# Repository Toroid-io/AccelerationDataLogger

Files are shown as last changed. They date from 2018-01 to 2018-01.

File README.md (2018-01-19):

# AccelerationDataLogger

**AccelerationDataLogger** provides a hardware-software bundle to
measure and log accelerations. Originally developed to measure
oscillations in engineering models, it may be used in the following
applications, among others:

 - Structural dynamics
 - Sports science
 - Simple vibration analysis
 - Fall detection
 - Wearables development
 - As an accelerometer playground

The board is capable of measuring **two accelerations simultaneously**
with a maximum sampling frequency of 800Hz, during 11 seconds. Longer
measurements are possible reducing the sampling rate, or using only one
accelerometer.

It currently uses jellybean parts as accelerometers. The board currently
supports the following breakout boards:
 - MPU6050 (GY-521 breakout)
 - ADXL345 (GY-291 and Sparkfun breakouts)

## Quick user manual
- Power the board using batteries or the USB cable.
- Fix the board into the structure or person.
- Calibrate the board by pressing the *Calibrate button*.
- Acquire the acceleration by pressing the *Acquire button*.
- Connect the board to your computer to download the data.

## The Hardware
You may find the KiCad schematic and board in the `Board` directory.

### Overview

The board does all the acquisition and storing procedure autonomously.
Hence, it may be battery powered during acquisition, and then connected
to a computer to download the data. In the current state, the board
requires at least 6.8V to work autonomously (this tension may be
provided by two LiPo cells or a 9V battery).

It has three pushable buttons, in order to reset the system, calibrate
the device and acquire data. A pushable switch enables or disables the
battery for autonomous mode.

The board may be connected to a computer using a USB micro-B cable.

That's all you need to know about the hardware!

### Memory

The board has 1MBit of RAM, where all the data is stored. Given that a
16-bit accelerometer provides 6 bytes of data for each measurement (plus
1 byte for the accelerometer ID), the board is capable of saving 18724
measurements.

That equals:
 - 11.7 seconds using two accelerometers at 800Hz
 - 23.4 seconds using one accelerometer at 800Hz
 - 6.24 minutes with one accelerometer at 50Hz
 - ...

## The Firmware

ChibiOS RTOS is used for the firmware. Tasks are used to separate the
acquisition of each sensor, write the RAM, and send measurements when
requested. Give a look into the `Firmware` folder.

## The acquisition software

A simple interface has been written in Qt C++, in order to download and
preview the data. The interface looks like this:

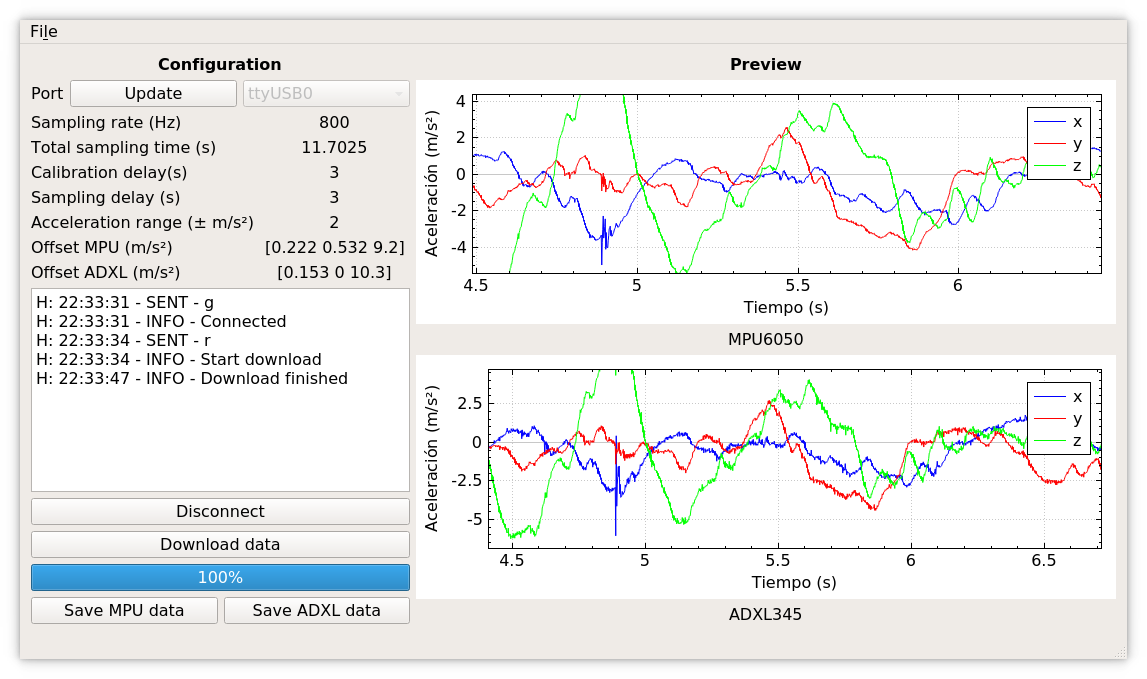
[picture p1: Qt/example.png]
Software screenshot


Currently, the interface only allows to connect and download the data
from the board. Future versions will allow the modification of some
parameters, such as the sampling frequency.

## I want one!

### Build One

Bare PCB

You can build your own AccelerationDataLogger. Mounting the PCB requires
average soldering skills (0603 footprints and LQFP packages), but it is
the cheap way to go.

You can get the PCB from [OSH
Park](https://oshpark.com/shared_projects/0VAEaJ3K), or generate your
own Gerbers from the PCB. The BOM is in the `Board` directory.

### Get one built

We can send you a populated PCB. Just contact us at `admin [at]
toroid.io` for a quote.

## Development

### Contribute

Do you want to add or request a new feature? Did you find a bug in the
code? Create an issue or a pull request! All contributions are welcome.

### Future features

A non-exhaustive list of future features:
 - Add support to more accelerometers
 - Use a coin cell to power the system autonomously
 - Reduce the size of the board
 - Implement other MEMS features (DMP, fall detection)

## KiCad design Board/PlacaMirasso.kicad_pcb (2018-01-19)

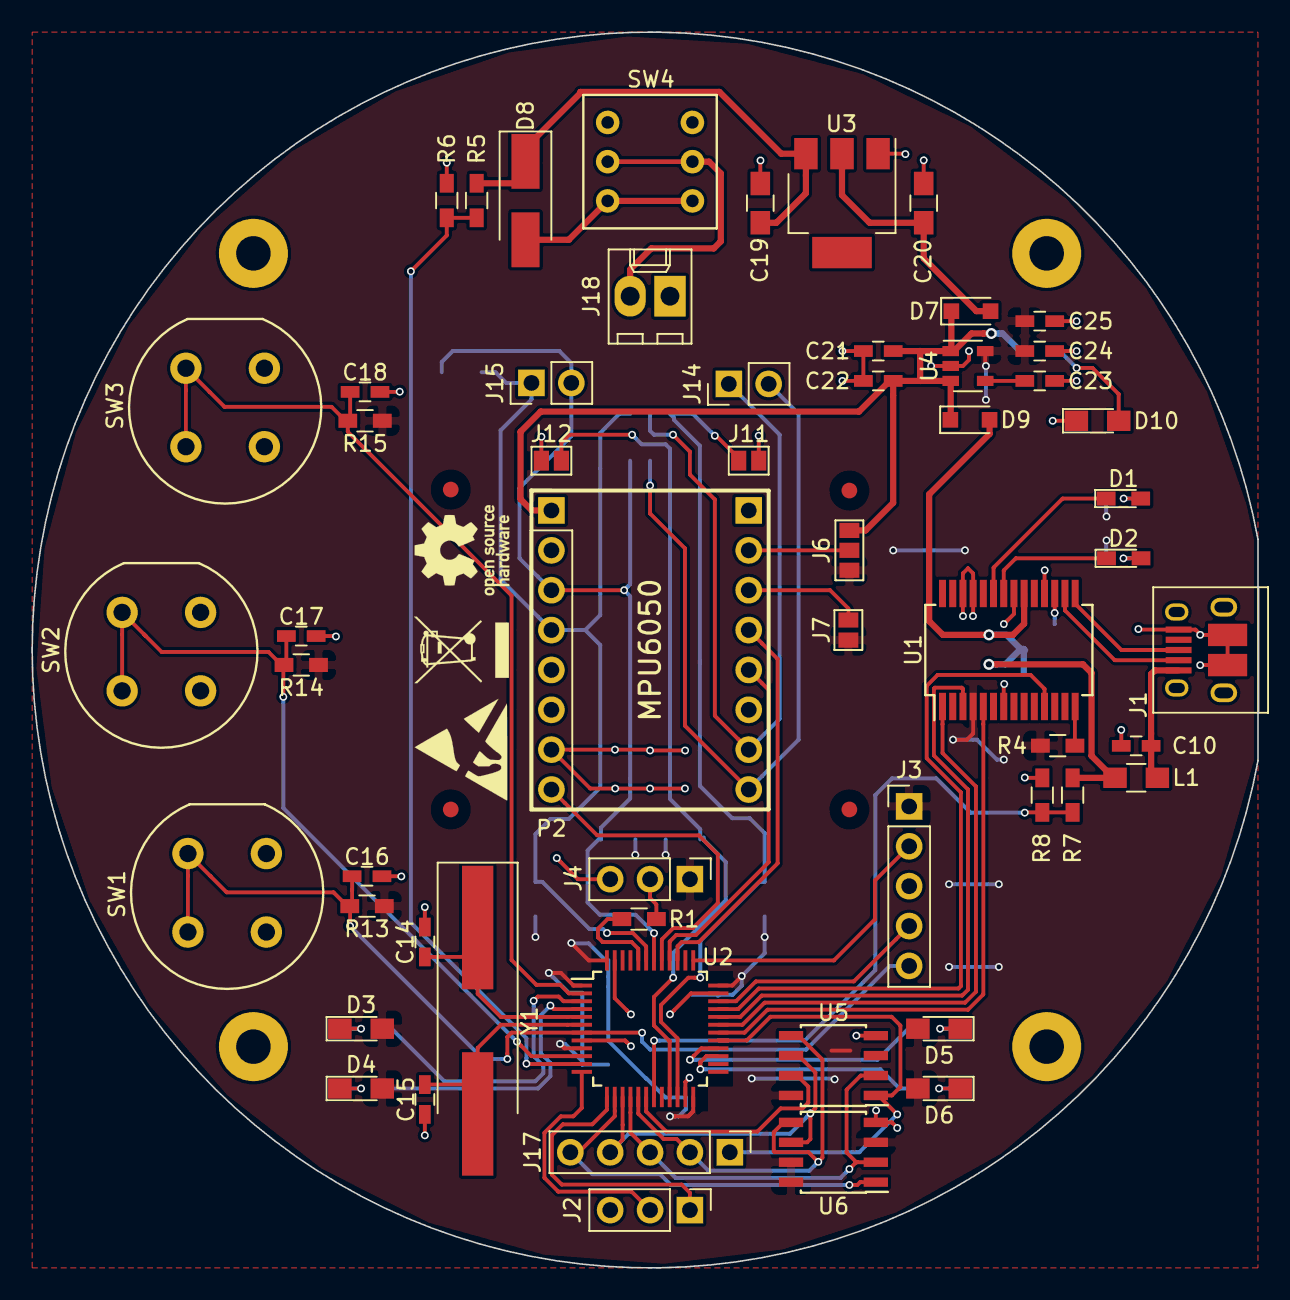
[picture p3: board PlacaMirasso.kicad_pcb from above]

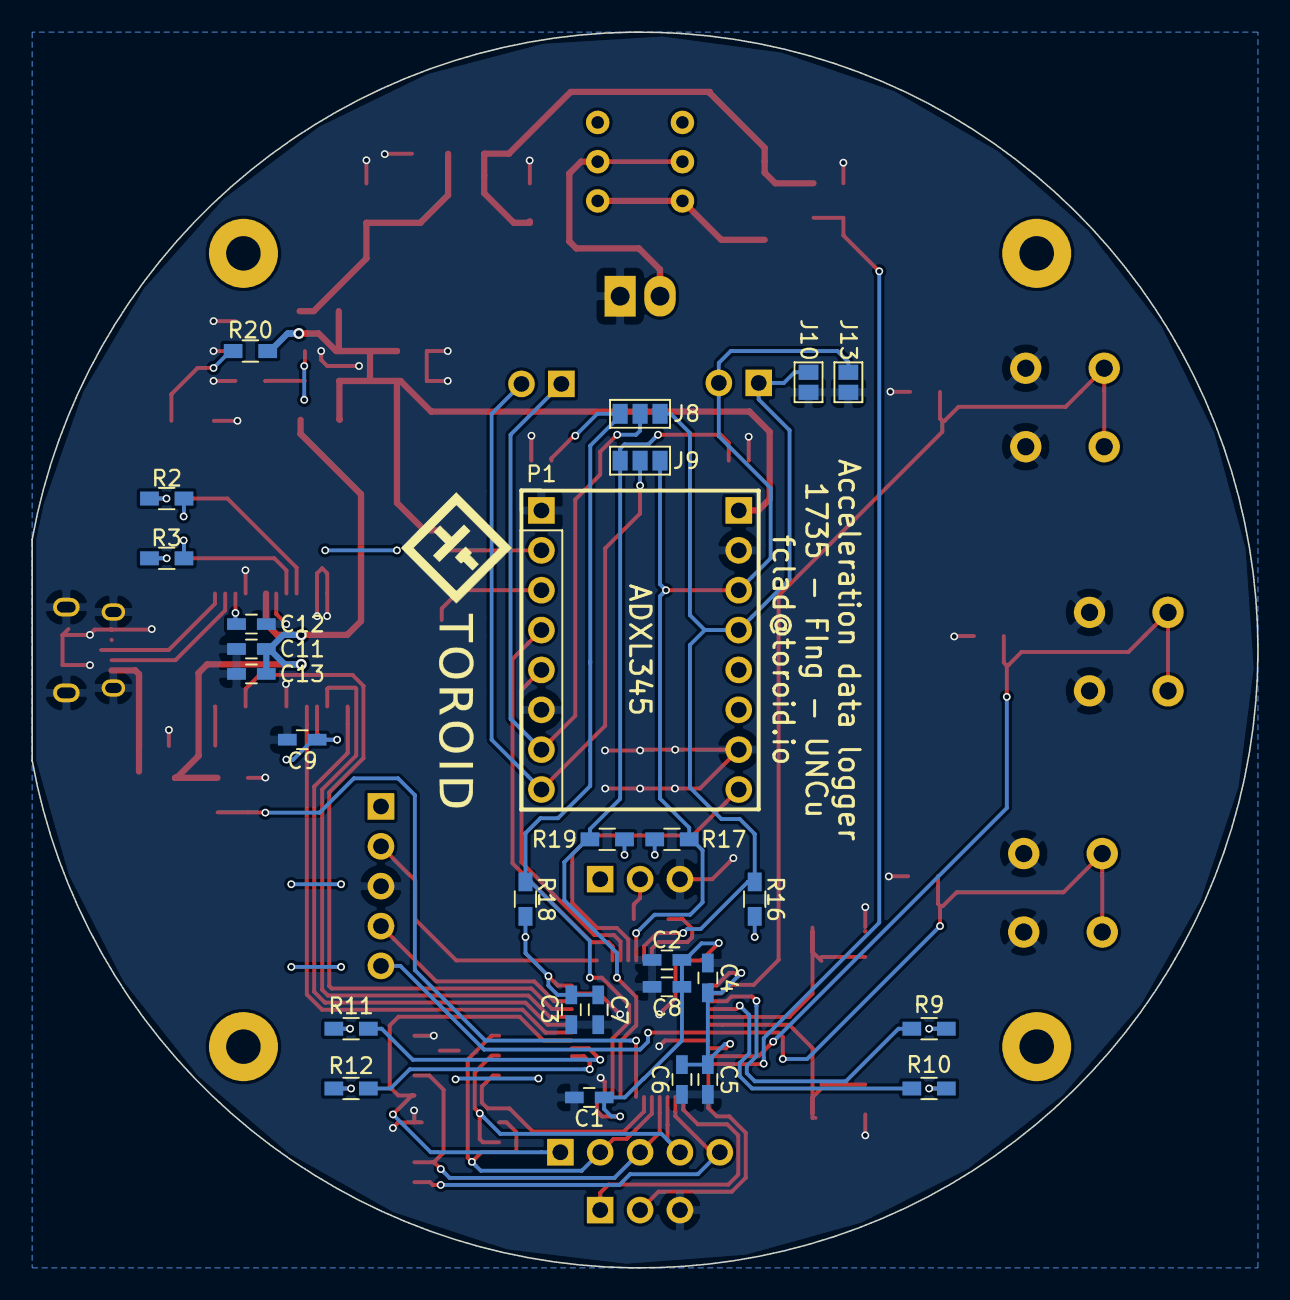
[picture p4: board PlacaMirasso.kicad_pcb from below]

Board: 2 copper layers, 78.1 x 78.7 mm, 93 parts (28 on the bottom side), 61 nets.

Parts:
C1, C2, C3, C4, C9, C11, C12, C16, C17, C18, C22, C25: 100nF; C_0603_HandSoldering
C5, C10, C23: 10nF_X7R; C_0603_HandSoldering
C6, C21, C24: 1uF_X5R; C_0603_HandSoldering
C7, C8, C13: 4.7uF; C_0603_HandSoldering
C14, C15: 10pF; C_0603_HandSoldering
C19, C20: 10uF; C_0805_HandSoldering
D1, D2: LED; LED_0603_HandSoldering
D3, D4, D5, D6, D10: LED; LED_0805_HandSoldering
D7, D9: BAT60JFILM; D_SOD-323_HandSoldering
D8: STPS2L30A; D_SMA_Handsoldering
J1: USB_OTG; USB_Micro-B_10103594-0001LF
J2: DEBUG; Pin_Header_Straight_1x03_Pitch2.54mm
J3: SWD; Pin_Header_Straight_1x05_Pitch2.54mm
J4: BOOT_JMP; Pin_Header_Straight_1x03_Pitch2.54mm
J6, J8, J9: GS3
J7, J10, J11, J12, J13: GS2
J14: ANALIZER_ADXL; Pin_Header_Straight_1x02_Pitch2.54mm
J15: ANALIZER_MPU; Pin_Header_Straight_1x02_Pitch2.54mm
J17: SPI_ANALYZER; Pin_Header_Straight_1x05_Pitch2.54mm
J18: BAT; Molex_KK-6410-02_02x2.54mm_Straight
L1: MI0805K400R-10; L_0805_HandSoldering
MNT1, MNT2, MNT3, MNT4: MountHole; MountingHole_2.2mm_M2_Pad
P1: ADXL345; Socket_Strip_Straight_1x08_Pitch2.54mm
P2: MPU_6050; Socket_Strip_Straight_1x08_Pitch2.54mm
R1, R4, R6: 10k; R_0603_HandSoldering
R2, R3, R9, R10, R11, R12, R20: 1k1; R_0603_HandSoldering
R5, R8: 47k; R_0603_HandSoldering
R7: 39k; R_0603_HandSoldering
R13, R14, R15: 100k; R_0603_HandSoldering
R16, R17, R18, R19: 2k2; R_0603_HandSoldering
SW1, SW2, SW3: SW_Push_Dual; Push_E-Switch_KS01Q01
SW4: SW_DPDT_x2; Pushbutton-MHPS2283-DPDT
U1: FT232RL; SSOP-28_5.3x10.2mm_Pitch0.65mm
U2: STM32F072CBTx; LQFP-48_7x7mm_Pitch0.5mm
U3: LD1117S50TR; SOT-223
U4: LD3985M33R_SOT23; SOT-23-5
U5: 23LCRAM; SOIC-8_3.9x4.9mm_Pitch1.27mm
U6: 25LC_EEPROM; SOIC-8_3.9x4.9mm_Pitch1.27mm
Y1: 9C-8.000MBBK-T; Crystal_SMD_HC49-SD_HandSoldering
fid1, fid2, fid3, fid4: fiducial; Fiducial_1mm_Dia_2.54mm_Outer_CopperTop

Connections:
+3V3: C1.1, C2.1, C3.1, C4.1, C5.1, C6.1, C7.1, C8.1, C9.1, C24.1, C25.1, D3.2, D4.2, D5.2, D6.2, J3.1, J4.1, J6.1, J7.1, R2.1, R3.1, R4.1, R13.1, R14.1, R15.1, R16.2, R17.2, R18.2, R19.2, U1.4, U2.1, U2.9, U2.24, U2.36, U2.48, U4.5, U5.8, U6.3, U6.7, U6.8
+5V: C21.1, C22.1, D7.1, D9.1, J6.3, P2.1, R20.1, U4.1, U4.3
/BOOT_0: J4.2, R1.2
/CS_ADXL: J7.2, P1.3
/CTS_uC: U1.3, U2.32
/DEBUG_RX_uC: J2.1, U2.13
/DEBUG_TX_uC: J2.2, U2.12
/E5V: C20.1, D7.2, U3.2
/I2C1_SCL: J9.1, J13.1, J15.2, P2.3, R17.1, U2.42
/I2C1_SDA: J8.1, J10.1, J15.1, P2.4, R16.1, U2.43
/I2C2_SCL: J9.3, J12.1, R19.1, U2.21
/I2C2_SDA: J8.3, J11.1, R18.1, U2.22
/INT1_ADXL: P1.4, U2.39
/INT2_ADXL: P1.5, U2.40
/INT_MPU: P2.8, U2.41
/LED_1: R9.2, U2.3
/LED_2: R10.2, U2.4
/LED_3: R11.2, U2.28
/LED_4: R12.2, U2.27
/RESET: C16.1, J3.5, R13.2, SW1.2, SW1.4, U2.7
/RTS_uC: U1.11, U2.33
/Rx_uC: U1.1, U2.31
/SCL_ADXL: J9.2, J14.2, P1.8
/SDA_ADXL: J8.2, J14.1, P1.7
/SPI1_CS_1: J17.5, U2.14, U6.1
/SPI1_CS_2: J17.1, U2.29, U5.1
/SPI1_HOLD: U2.18, U5.7
/SPI1_MISO: J17.3, U2.16, U5.2, U6.2
/SPI1_MOSI: J17.2, U2.17, U5.5, U6.5
/SPI1_SCK: J17.4, U2.15, U5.6, U6.6
/SWCLK: J3.2, U2.37
/SWDIO: J3.4, U2.34
/Tx_uC: U1.5, U2.30
/U5V: C11.1, C13.1, D9.2, L1.1, R7.1, U1.20
/USR_BTN_1: C17.1, R14.2, SW2.2, SW2.4, U2.10
/USR_BTN_2: C18.1, R15.2, SW3.2, SW3.4, U2.2
/VBAT_ADC: R5.2, R6.1, U2.11
/VCC_ADXL: J6.2, P1.2
/VIN: C19.1, D8.1, R5.1, U3.3
/VUSB_ADC: R7.2, R8.1, U2.19
GND: C1.2, C2.2, C3.2, C4.2, C5.2, C6.2, C7.2, C8.2, C9.2, C10.2, C11.2, C12.2, C13.2, C14.2, C15.2, C16.2, C17.2, C18.2, C19.2, C20.2, C21.2, C22.2, C23.2, C24.2, C25.2, D10.1, J1.5, J1.6, J2.3, J3.3, J4.3, J10.2, J11.2, J12.2, J13.2, J18.1, P1.1, P1.6, P2.2, P2.7, R6.2, R8.2, SW1.1, SW1.3, SW2.1, SW2.3, SW3.1, SW3.3, U1.7, U1.18, U1.21, U1.25, U1.26, U2.8, U2.23, U2.35, U2.47, U3.1, U4.2, U5.4, U6.4
unnamed: C10.1, J1.1, L1.2
unnamed: C12.1, U1.17
unnamed: C14.1, U2.5, Y1.1
unnamed: C15.1, U2.6, Y1.2
unnamed: C23.1, U4.4
unnamed: D1.1, U1.23
unnamed: D1.2, R2.2
unnamed: D2.1, U1.22
unnamed: D2.2, R3.2
unnamed: D3.1, R9.1
unnamed: D4.1, R10.1
unnamed: D5.1, R11.1
unnamed: D6.1, R12.1
unnamed: D8.2, SW4.3, SW4.6
unnamed: D10.2, R20.2
unnamed: J1.2, U1.16
unnamed: J1.3, U1.15
unnamed: J18.2, SW4.2, SW4.5
unnamed: R1.1, U2.44
unnamed: R4.2, U1.14

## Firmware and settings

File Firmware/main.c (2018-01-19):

/* TODO
 * - Config variable sensors range (EEPROM config)
 * - Fix UART unhandled exception when system is not compiled with debug options
 */
#include "ch.h"
#include "hal.h"
#include "ChibiOS/os/hal/lib/streams/chprintf.h"
#include <string.h>
#include "MEMS/MPU6050.h"
#include "MEMS/ADXL345.h"
#include "EEPROM/StaticSystemConfig.h"


/*===========================================================================*/
/* Global variables - RTOS stuff                                             */
/*===========================================================================*/

volatile enum state {IDLE,
	CALIBRATION,
	START_ACQUISITION,
	ACQUISITION,
	DOWNLOAD_CONFIG,
	SAVE_CONFIG,
	PRINT_DATA,
	PRINT_CONFIG} systemState;
static MUTEX_DECL(systemState_mutex);

struct configStructure sysConf;

/* the mailboxes are used to send information into the spi thread */
#define NUM_BUFFERS 4
#define BUFFERS_SIZE 8
static char buffers[NUM_BUFFERS][BUFFERS_SIZE];
static msg_t free_buffers_queue[NUM_BUFFERS];
static mailbox_t free_buffers;
static msg_t filled_buffers_queue[NUM_BUFFERS];
static mailbox_t filled_buffers;

/* recvBuffer is used to store data coming from the UART (configs) */
uint8_t recvBuffer[32];

#define SPI_RAM_SIZE 128*1024
/* Amount of memory used in the SPI RAM */
/* This variable does not need a mutex by design. Mutual exclusion is handled by
 * systemState
 */
volatile int32_t memoryCounter;

/* Various semaphores to synchronize stuff */
static BSEMAPHORE_DECL(printMutex, 1);
static threads_queue_t threadQueue;

/* ADC variables used to test USB, Battery voltage, VRefInt, Temp */
#define ADC_GRP_NUM_CHANNELS   2
#define ADC_GRP_BUF_DEPTH      128
static adcsample_t samples[ADC_GRP_NUM_CHANNELS * ADC_GRP_BUF_DEPTH];

/*===========================================================================*/
/* Callbacks                                                                 */
/*===========================================================================*/

/* Triggered when the calibration button is released.*/
static void extcb1(EXTDriver *extp, expchannel_t channel) {
  (void)extp;
  (void)channel;
  chSysLockFromISR();
  if (systemState == IDLE)
	  systemState = CALIBRATION;
  chSysUnlockFromISR();
}

/* Triggered when the acquisition button is released.*/
static void extcb2(EXTDriver *extp, expchannel_t channel) {
  (void)extp;
  (void)channel;
  chSysLockFromISR();
  if (systemState == IDLE)
	  systemState = START_ACQUISITION;
  chSysUnlockFromISR();
}

static void led2off(void *arg);
static void gpt3cb(GPTDriver *gptp) {
	(void)gptp;
	static virtual_timer_t vt;
	palClearPad(GPIOC, GPIOC_LED_2);
	chSysLockFromISR();
	chThdDequeueAllI(&threadQueue, 0);
	/* LED2 set to OFF after 800uS.*/
	chVTResetI(&vt);
	chVTSetI(&vt, US2ST(800), led2off, NULL);
	chSysUnlockFromISR();
}

/*
 * This callback is invoked when a transmission buffer has been completely
 * read by the driver.
 */
static void txend1(UARTDriver *uartp) {
  (void)uartp;
  //palSetPad(GPIOC, GPIOC_LED4);
}

/*
 * This callback is invoked when a transmission has physically completed.
 */
static void led3off(void *arg);
static void txend2(UARTDriver *uartp) {
  (void)uartp;
  static virtual_timer_t vt3;
  palClearPad(GPIOB, GPIOB_LED_3);
  chSysLockFromISR();
  chVTResetI(&vt3);
  chVTSetI(&vt3, US2ST(200), led3off, NULL);
  chSysUnlockFromISR();
}

/*
 * This callback is invoked on a receive error, the errors mask is passed
 * as parameter.
 */
static void rxerr(UARTDriver *uartp, uartflags_t e) {
  (void)uartp;
  (void)e;
}

/*
 * This callback is invoked when a character is received but the application
 * was not ready to receive it, the character is passed as parameter.
 */
static void rxchar(UARTDriver *uartp, uint16_t c) {
  (void)uartp;
  (void)c;
  chSysLockFromISR();
  if (systemState != IDLE) {
	  chSysUnlockFromISR();
	  return;
  }
  switch (c) {
  case 'r':
  case 'R':
	  systemState = PRINT_DATA;
	  chBSemSignalI(&printMutex);
	  break;
  case 'g':
  case 'G':
	  systemState = PRINT_CONFIG;
	  chBSemSignalI(&printMutex);
	  break;
  case 'c':
  case 'C':
	  systemState = DOWNLOAD_CONFIG;
	  uartStartSendI(&UARTD1, 15, "--Send Config--");
	  uartStartReceiveI(&UARTD1,
			    sizeof(struct configStructure),
			    (void *)recvBuffer);
	  break;
  default:
	  break;
  }
  chSysUnlockFromISR();
}

/*
 * This callback is invoked when a receive buffer has been completely written.
 */
static void rxend(UARTDriver *uartp) {
  (void)uartp;
  chSysLockFromISR();
  if (systemState != DOWNLOAD_CONFIG)
	  osalSysHalt("UART rx was not expected");
  if(checkSystemConfig((struct configStructure *)recvBuffer)) {
	  uartStartSendI(&UARTD1, 16, "--Config ERROR--");
	  systemState = IDLE;
  } else {
	  uartStartSendI(&UARTD1, 13, "--Config OK--");
	  systemState = SAVE_CONFIG;
	  memcpy(&sysConf, recvBuffer, sizeof(struct configStructure));
  }
  chSysUnlockFromISR();
}

/*
 * This callback is invoked when configured timeout reached.
 */
static void rxtimeout(UARTDriver *uartp) {
  (void)uartp;
  chSysLockFromISR();
  /* We can get here because commands triggered this interrupt instead of data */
  if (systemState == DOWNLOAD_CONFIG) {
	  uartStopReceiveI(&UARTD1);
	  uartStartSendI(&UARTD1, 18, "--Config TIMEOUT--");
	  systemState = IDLE;
  }
  chSysUnlockFromISR();
}

/*===========================================================================*/
/* Peripherals config structures                                             */
/*===========================================================================*/

static const I2CConfig i2ccfg1 = {
	0x20803C54, // Normal mode, 100kHz
	0,
	0
};

static const I2CConfig i2ccfg2 = {
	0x80201619, // Normal mode, 100kHz
	0,
	0
};
static const SPIConfig eepromSPI = {
	NULL,
	GPIOA,
	GPIOA_SPI_CS_1,
	SPI_CR1_BR_2 | SPI_CR1_BR_1,
	SPI_CR2_DS_2 | SPI_CR2_DS_1 | SPI_CR2_DS_0
};

static const SPIConfig ramSPI = {
	NULL,
	GPIOA,
	GPIOA_SPI_CS_2,
	SPI_CR1_BR_2 | SPI_CR1_BR_1,
	SPI_CR2_DS_2 | SPI_CR2_DS_1 | SPI_CR2_DS_0
};

static const EXTConfig extcfg = {
  {
    {EXT_CH_MODE_RISING_EDGE | EXT_CH_MODE_AUTOSTART | EXT_MODE_GPIOA, extcb1},
    {EXT_CH_MODE_DISABLED, NULL},
    {EXT_CH_MODE_DISABLED, NULL},
    {EXT_CH_MODE_DISABLED, NULL},
    {EXT_CH_MODE_DISABLED, NULL},
    {EXT_CH_MODE_DISABLED, NULL},
    {EXT_CH_MODE_DISABLED, NULL},
    {EXT_CH_MODE_DISABLED, NULL},
    {EXT_CH_MODE_DISABLED, NULL},
    {EXT_CH_MODE_DISABLED, NULL},
    {EXT_CH_MODE_DISABLED, NULL},
    {EXT_CH_MODE_DISABLED, NULL},
    {EXT_CH_MODE_DISABLED, NULL},
    {EXT_CH_MODE_RISING_EDGE | EXT_CH_MODE_AUTOSTART | EXT_MODE_GPIOC, extcb2},
    {EXT_CH_MODE_DISABLED, NULL},
    {EXT_CH_MODE_DISABLED, NULL},
    {EXT_CH_MODE_DISABLED, NULL},
    {EXT_CH_MODE_DISABLED, NULL},
    {EXT_CH_MODE_DISABLED, NULL},
    {EXT_CH_MODE_DISABLED, NULL},
    {EXT_CH_MODE_DISABLED, NULL},
    {EXT_CH_MODE_DISABLED, NULL},
    {EXT_CH_MODE_DISABLED, NULL}
  }
};

static const GPTConfig gpt3cfg = {
  100000, // 100kHz timer clock.
  gpt3cb,
  0, 0
};

static const ADCConversionGroup adcgrpcfg = {
  TRUE,
  ADC_GRP_NUM_CHANNELS,
  NULL,
  NULL,
  ADC_CFGR1_CONT | ADC_CFGR1_RES_12BIT,             /* CFGR1 */
  ADC_TR(0, 0),                                     /* TR */
  ADC_SMPR_SMP_239P5,                               /* SMPR */
  ADC_CHSELR_CHSEL1 | ADC_CHSELR_CHSEL9
};

static UARTConfig uart_cfg_1 = {
  txend1,
  txend2,
  rxend,
  rxchar,
  rxerr,
  rxtimeout,
  115200*3,
  115200,
  USART_CR1_RTOIE,
  USART_CR2_LINEN | USART_CR2_RTOEN,
  0
};

/*===========================================================================*/
/* Functions                                                                 */
/*===========================================================================*/
void modifyAxis(int16_t *ax, int16_t *ay, int16_t *az)
{
	uint16_t tmp;
	*az= -*az;
	tmp = *ax;
	*ax = -*ay;
	*ay = -tmp;
}

void saturateInt16(int32_t *atmp, int16_t *acc)
{
	for (uint8_t i = 0; i < 3; ++i) {
		if (atmp[i] > INT16_MAX)
			acc[i] = INT16_MAX;
		else if (atmp[i] < INT16_MIN)
			acc[i] = INT16_MIN;
		else
			acc[i] = (int16_t)atmp[i];
	}
}

void exponentialFilter(int32_t *atmp, int32_t *g, int16_t *acc)
{
	/* Numerator and denominator values of the exponential filter */
	/* The calculation of the numerator gives a filter time-constant of 75 ms */
	int32_t num, den;
	den = 1000;
	num = (7500 * den) / (7500 + 100000 / sysConf.samplingSpeed);
	for (uint8_t i = 0; i < 3; ++i) {
	    g[i] = (g[i] * num + (den - num) * acc[i]) / den;
	    atmp[i] = acc[i] - g[i];
	}
	saturateInt16(atmp, acc);
}

static void led2off(void *arg) {
  (void)arg;
  palSetPad(GPIOC, GPIOC_LED_2);
}

static void led3off(void *arg) {
  (void)arg;
  palSetPad(GPIOB, GPIOB_LED_3);
}


static void blinkAllLeds(void){
  for (int i = 0; i < 2; ++i) {
    palClearPad(GPIOC, GPIOC_LED_1);
    palClearPad(GPIOC, GPIOC_LED_2);
    palClearPad(GPIOB, GPIOB_LED_3);
    palClearPad(GPIOB, GPIOB_LED_4);
    osalThreadSleepMilliseconds(100);
    palSetPad(GPIOC, GPIOC_LED_1);
    palSetPad(GPIOC, GPIOC_LED_2);
    palSetPad(GPIOB, GPIOB_LED_3);
    palSetPad(GPIOB, GPIOB_LED_4);
    osalThreadSleepMilliseconds(100);
  }
}

static void I2CInit(void)
{
	/*
	 * Check if the I2C is clogged and send some SCK pulses to release it
	 */

	if (!palReadPad(GPIOB, GPIOB_I2C1_SDA)) {
		for (int i  = 0; i < 16; ++i) {
			palClearPad(GPIOB, GPIOB_I2C1_SCL);
			osalThreadSleepMilliseconds(1);
			palSetPad(GPIOB, GPIOB_I2C1_SCL);
			osalThreadSleepMilliseconds(1);
		}
	}
	if (!palReadPad(GPIOB, GPIOB_I2C2_SDA)) {
		for (int i  = 0; i < 16; ++i) {
			palClearPad(GPIOB, GPIOB_I2C2_SCL);
			osalThreadSleepMilliseconds(1);
			palSetPad(GPIOB, GPIOB_I2C2_SCL);
			osalThreadSleepMilliseconds(1);
		}
	}

	/*
	 * Activates the I2C driver in hardware mode
	 */
	palSetPadMode(GPIOB, GPIOB_I2C1_SCL, PAL_MODE_ALTERNATE(1) |
		      PAL_STM32_OSPEED_HIGHEST | PAL_STM32_OTYPE_OPENDRAIN | PAL_STM32_PUPDR_PULLUP);
	palSetPadMode(GPIOB, GPIOB_I2C1_SDA, PAL_MODE_ALTERNATE(1) |
		      PAL_STM32_OSPEED_HIGHEST | PAL_STM32_OTYPE_OPENDRAIN | PAL_STM32_PUPDR_PULLUP);
	palSetPadMode(GPIOB, GPIOB_I2C2_SCL, PAL_MODE_ALTERNATE(1) |
		      PAL_STM32_OSPEED_HIGHEST | PAL_STM32_OTYPE_OPENDRAIN | PAL_STM32_PUPDR_PULLUP);
	palSetPadMode(GPIOB, GPIOB_I2C2_SDA, PAL_MODE_ALTERNATE(1) |
		      PAL_STM32_OSPEED_HIGHEST | PAL_STM32_OTYPE_OPENDRAIN | PAL_STM32_PUPDR_PULLUP);
	i2cStart(&I2CD1, &i2ccfg1);
	i2cStart(&I2CD2, &i2ccfg2);
}

static void calibrateSensors(void)
{
  uint16_t i;
  int16_t ax, ay, az;
  int32_t calibrationAccADXL[3] = {0, 0, 0};
  int32_t calibrationAccMPU[3] = {0, 0, 0};

  /* Calibration loop */
  for (i = 0; i < 128; ++i) {
    palClearPad(GPIOC, GPIOC_LED_2);
    chThdSleepMilliseconds(10);
    palSetPad(GPIOC, GPIOC_LED_2);
    MPU6050_getAcceleration(&ax, &ay, &az);
    calibrationAccMPU[0] += ax;
    calibrationAccMPU[1] += ay;
    calibrationAccMPU[2] += az;
    ADXL345_getAcceleration(&ax, &ay, &az);
    modifyAxis(&ax, &ay, &az);
    calibrationAccADXL[0] += ax;
    calibrationAccADXL[1] += ay;
    calibrationAccADXL[2] += az;
    chThdSleepMilliseconds(10);
  }

  sysConf.calibrationMPU[0] = calibrationAccMPU[0] / 128;
  sysConf.calibrationMPU[1] = calibrationAccMPU[1] / 128;
  sysConf.calibrationMPU[2] = calibrationAccMPU[2] / 128;

  sysConf.calibrationADXL[0] = calibrationAccADXL[0] / 128;
  sysConf.calibrationADXL[1] = calibrationAccADXL[1] / 128;
  sysConf.calibrationADXL[2] = calibrationAccADXL[2] / 128;

  saveSystemConfigEEPROM(&eepromSPI, &sysConf);

}

void createMailboxes(void)
{
	chMBObjectInit(&filled_buffers, filled_buffers_queue, NUM_BUFFERS);
	chMBObjectInit(&free_buffers, free_buffers_queue, NUM_BUFFERS);
	for (uint8_t i = 0; i < NUM_BUFFERS; i++)
		(void)chMBPost(&free_buffers, (msg_t)&buffers[i], TIME_INFINITE);
}

static void resetAllMailboxes(void)
{
	chMBReset(&free_buffers);
	chMBReset(&filled_buffers);
	createMailboxes();
}

static void sensorStartup(void)
{
	/* Initialize MPU */
	MPU6050_reset();
	chThdSleepMilliseconds(100);
	MPU6050_resetGyroscopePath();
	MPU6050_resetAccelerometerPath();
	MPU6050_resetTemperaturePath();
	chThdSleepMilliseconds(100);
	MPU6050_initialize();
	MPU6050_setStandbyXGyroEnabled(true);
	MPU6050_setStandbyYGyroEnabled(true);
	MPU6050_setStandbyZGyroEnabled(true);
	chThdSleepMilliseconds(100);
	// verify connection
	while (!MPU6050_testConnection()) {
		chprintf((BaseSequentialStream *)&SD2,"MPU FAIL\r\n");
		chThdSleepMilliseconds(1000);
	}
	chprintf((BaseSequentialStream *)&SD2,"MPU OK\r\n");

	/* Initialize ADXL345 */
	ADXL345_initialize();
	chThdSleepMilliseconds(100);
	// verify connection
	while (!ADXL345_testConnection()) {
		chprintf((BaseSequentialStream *)&SD2,"ADXL FAIL\r\n");
		chThdSleepMilliseconds(1000);
	}
	chprintf((BaseSequentialStream *)&SD2,"ADXL OK\r\n");
}

void getVoltages(uint16_t *vusb, uint16_t *vbat)
{
	uint32_t usbtmp = 0;
	uint32_t battmp = 0;
	/* Samples are alternating: vbat, vusb, vbat... */
	for(uint8_t i = 0; i < ADC_GRP_BUF_DEPTH; ++i) {
		battmp += samples[ADC_GRP_NUM_CHANNELS*i];
		usbtmp += samples[ADC_GRP_NUM_CHANNELS*i + 1];
	}
	battmp /= ADC_GRP_BUF_DEPTH;
	usbtmp /= ADC_GRP_BUF_DEPTH;

	/* Reference voltage is corrected to handle resistor offset
	 * (instead of 3300). Voltages are in mV.
	 */
	battmp = (battmp * 3394 * 57) / (4096 * 10);
	usbtmp = (usbtmp * 3327 * 86) / (4096 * 47);

	*vusb = (uint16_t)usbtmp;
	*vbat = (uint16_t)battmp;

	////chprintf((BaseSequentialStream *)&SD2,"USB: %u - BAT: %u\r\n",
	//	 *vusb, *vbat);
	return;
}

uint8_t checkVoltageLevel(void)
{
	uint16_t vusb, vbat;
	getVoltages(&vusb, &vbat);
	/* When running with USB voltage should not be a problem */
	if (vusb > 4000)
		return 0;
	  /* When running on batteries, 6.8V seems a logic voltage threshold */
	if (vbat < 6800) {
		return 1;
	}
	return 0;
}


/*===========================================================================*/
/* Threads                                                                   */
/*===========================================================================*/
/*
 * State machine thread
 */
static THD_WORKING_AREA(waThread0, 0x200);
static THD_FUNCTION(Thread0, arg) {
	(void)arg;
	uint32_t timerPeriod;
	while (true) {
		chMtxLock(&systemState_mutex);
		switch(systemState) {
		case IDLE:
		default:
			break;
		case CALIBRATION:
			chprintf((BaseSequentialStream *)&SD2,"Calibration...\r\n");
			for (uint8_t i = 0; i < 10*sysConf.calibrationDelay; i++) {
				palClearPad(GPIOC, GPIOC_LED_2);
				chThdSleepMilliseconds(50);
				palSetPad(GPIOC, GPIOC_LED_2);
				chThdSleepMilliseconds(50);

			}
			calibrateSensors();
			chprintf((BaseSequentialStream *)&SD2,"Calibration DONE\r\n");
			systemState = IDLE;
			break;
		case START_ACQUISITION:
			chprintf((BaseSequentialStream *)&SD2,"Acquisition...\r\n");
			for (uint8_t i = 0; i < 10*sysConf.acquisitionDelay; i++) {
				palClearPad(GPIOC, GPIOC_LED_2);
				chThdSleepMilliseconds(50);
				palSetPad(GPIOC, GPIOC_LED_2);
				chThdSleepMilliseconds(50);

			}
			memoryCounter = 0;
			systemState = ACQUISITION;
			/* Calculate the new timer period */
			timerPeriod = 100000/sysConf.samplingSpeed - 1;
			chprintf((BaseSequentialStream *)&SD2,"Timer period %u\r\n", (uint16_t)timerPeriod);
			/* Start the timer */
			gptStartContinuous(&GPTD3, (uint16_t) timerPeriod);
			break;
		case ACQUISITION:
			/* Nothing to do here
			 * State changement will be done in the RAM write task
			 */
			break;
		case DOWNLOAD_CONFIG:
			/* Nothing to do here
			 * State changement will be done in the UART callbacks
			 */
			break;
		case SAVE_CONFIG:
			/* We have a new config, save it in the EEPROM */
			saveSystemConfigEEPROM(&eepromSPI, &sysConf);
			/* Discard all measurements */
			memoryCounter = 0;
			systemState = IDLE;
			break;
		case PRINT_DATA:
			/* Nothing to do here
			 * Mutex will be released in ISR callback
			 * State will change in UART write task
			 */
			break;
		case PRINT_CONFIG:
			/* Nothing to do here
			 * Mutex will be released in ISR callback
			 * State will change in UART write task
			 */
			break;
		}
		chMtxUnlock(&systemState_mutex);
		chThdSleepMilliseconds(100);
	}
}
/*
 * MPU6050  polling thread.
 */
static THD_WORKING_AREA(waThread1, 0x200);
static THD_FUNCTION(Thread1, arg) {

  (void)arg;
  void *pbuf;

  chRegSetThreadName("MPU6050_Poll");

  int16_t acc[3];
  int32_t atmp[3];
  int32_t g[3] = {0, 0, 0};

  chprintf((BaseSequentialStream *)&SD2,"MPU Thread\r\n");

  while (true) {
    /* wait until the timer starts */
    chSysLock();
    chThdEnqueueTimeoutS(&threadQueue, TIME_INFINITE);
    chSysUnlock();

    MPU6050_getAcceleration(acc, acc + 1, acc + 2);

    switch(sysConf.MPUfilterType) {
    case  0:
	    /* Do nothing, send the accelerations as they are sampled */
	    break;
    case 1:
	    atmp[0] = acc[0] - sysConf.calibrationMPU[0];
	    atmp[1] = acc[1] - sysConf.calibrationMPU[1];
	    atmp[2] = acc[2] - sysConf.calibrationMPU[2];

	    saturateInt16(atmp, acc);
	    break;
    case 2:
	    exponentialFilter(atmp, g, acc);
	    break;
    default:
	    osalSysHalt("Invalid filter type in MPU Thread");
	    break;
    }

    if (chMBFetch(&free_buffers, (msg_t *)&pbuf, TIME_INFINITE) == MSG_OK) {
      char *message = (char *)pbuf;
      message[0]  = 'M';
      message[1]  = (char)((acc[0]) & 0xFF);
      message[2]  = (char)((acc[0] >> 8) & 0xFF);
      message[3]  = (char)((acc[1]) & 0xFF);
      message[4]  = (char)((acc[1] >> 8) & 0xFF);
      message[5]  = (char)((acc[2]) & 0xFF);
      message[6]  = (char)((acc[2] >> 8) & 0xFF);
      (void)chMBPost(&filled_buffers, (msg_t)pbuf, TIME_INFINITE);
    }
  }
}
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
int main(void) {

  /*
   * System initializations.
   * - HAL initialization, this also initializes the configured device drivers
   *   and performs the board-specific initializations.
   * - Kernel initialization, the main() function becomes a thread and the
   *   RTOS is active.
   */
  halInit();
  chSysInit();

   /* Activates the UART and SERIAL (debug) drivers */
  SYSCFG->CFGR1 |= SYSCFG_CFGR1_USART1TX_DMA_RMP;
  SYSCFG->CFGR1 |= SYSCFG_CFGR1_USART1RX_DMA_RMP;
  uartStart(&UARTD1, &uart_cfg_1);
  sdStart(&SD2, NULL);

  uartAcquireBus(&UARTD1);
  uartStartSend(&UARTD1, 13, "Starting...\r\n");
  uartReleaseBus(&UARTD1);

  chprintf((BaseSequentialStream *)&SD2,"Starting...\r\n");
  chprintf((BaseSequentialStream *)&SD2, "SYSCLK=%u\r\n", STM32_SYSCLK);

  /*
   * Blink all the LEDs
   */
  blinkAllLeds();

  /* Start ADC, wait for some samples and check for battery level*/
  adcStart(&ADCD1, NULL);
  adcStartConversion(&ADCD1, &adcgrpcfg, samples, ADC_GRP_BUF_DEPTH);
  chThdSleepMilliseconds(100);
  if (checkVoltageLevel())
	  goto low_voltage_handler;

  /* Get and verify system config from EEPROM */
  while (restoreSystemConfigEEPROM(&eepromSPI, &sysConf)) {
	  chprintf((BaseSequentialStream *)&SD2,"Invalid config in EEPROM\r\n");
	  chprintf((BaseSequentialStream *)&SD2,"Writing a new one...\r\n");
	  saveDefaultConfigEEPROM(&eepromSPI);
  }
  chprintf((BaseSequentialStream *)&SD2,"Good system config in EEPROM\r\n");

  printSystemConfig(&sysConf, (BaseSequentialStream *)&SD2);

  I2CInit();

  sensorStartup();

  /* Initialize the timer */
  gptStart(&GPTD3, &gpt3cfg);

  /* Create and pre-fill the mailboxes.*/
  createMailboxes();

  /* Init thread queue (unlock accelerometer threads from interruption) */
  osalThreadQueueObjectInit(&threadQueue);

  systemState = IDLE;

  /* We've finished the initialization */
  blinkAllLeds();

  /* Creates the threads */
  chThdCreateStatic(waThread0, sizeof(waThread0), NORMALPRIO+5, Thread0, NULL); // State machine thread
  chThdCreateStatic(waThread1, sizeof(waThread1), NORMALPRIO+3, Thread1, NULL); // MPU goes always first
  chThdCreateStatic(waThread2, sizeof(waThread2), NORMALPRIO+2, Thread2, NULL); // ADXL
  chThdCreateStatic(waThread3, sizeof(waThread3), NORMALPRIO,   Thread3, NULL); // SPI
  chThdCreateStatic(waThread4, sizeof(waThread4), NORMALPRIO-5, Thread4, NULL); // Serial printer

  /* Enable external (button) interrupts */
  extStart(&EXTD1, &extcfg);

  /* Normal main() thread activity.
   * Blink leds and handle all catastrophic errors.
   */
  while (true) {
	  palClearPad(GPIOC, GPIOC_LED_1);
	  osalThreadSleepMilliseconds(500);
	  palSetPad(GPIOC, GPIOC_LED_1);
	  osalThreadSleepMilliseconds(500);

	  /* Check if voltage levels are good */
	  if (checkVoltageLevel()) {
low_voltage_handler:
		  /* Give a huge priority and run an infinite loop.
		   * Nobody will preempt us */
		  chThdSetPriority(NORMALPRIO+10);
		  adcStopConversion(&ADCD1);
		  adcStop(&ADCD1);
		  while (true) {
			  for (uint32_t i = 0; i < 400000; ++i);
			  palSetPad(GPIOB, GPIOB_LED_4);
			  for (uint32_t i = 0; i < 400000; ++i);
			  palClearPad(GPIOB, GPIOB_LED_4);

		  }
	  }
  }
}

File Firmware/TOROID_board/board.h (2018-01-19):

/*
    ChibiOS - Copyright (C) 2006..2016 Giovanni Di Sirio

    Licensed under the Apache License, Version 2.0 (the "License");
    you may not use this file except in compliance with the License.
    You may obtain a copy of the License at

        http://www.apache.org/licenses/LICENSE-2.0

    Unless required by applicable law or agreed to in writing, software
    distributed under the License is distributed on an "AS IS" BASIS,
    WITHOUT WARRANTIES OR CONDITIONS OF ANY KIND, either express or implied.
    See the License for the specific language governing permissions and
    limitations under the License.
*/

/*
 * This file has been automatically generated using ChibiStudio board
 * generator plugin. Do not edit manually.
 */

#ifndef BOARD_H
#define BOARD_H

/*
 * Board identifier.
 */
#define BOARD_ST_NUCLEO_F072RB
#define BOARD_NAME                  "TOROID Acceleration Data Logger"

/*
 * Board oscillators-related settings.
 * NOTE: LSE not fitted.
 * NOTE: HSE fitted with 8Mhz Quartz
 */
#if !defined(STM32_LSECLK)
#define STM32_LSECLK                0U
#endif

#define STM32_LSEDRV                (3U << 3U)

#if !defined(STM32_HSECLK)
#define STM32_HSECLK                8000000U
#endif

/*
 * MCU type as defined in the ST header.
 */
#define STM32F072xB

/*
 * IO pins assignments.
 */
#define GPIOA_USR_BTN_1             0U
#define GPIOA_VBAT_ADC              1U
#define GPIOA_DEBUG_TX              2U
#define GPIOA_DEBUG_RX              3U
#define GPIOA_SPI_CS_1              4U
#define GPIOA_SPI_SCK               5U
#define GPIOA_SPI_MISO              6U
#define GPIOA_SPI_MOSI              7U
#define GPIOA_SPI_CS_2              8U
#define GPIOA_USART_TX              9U
#define GPIOA_USART_RX              10U
#define GPIOA_USART_CTS             11U
#define GPIOA_USART_RTS             12U
#define GPIOA_SWDIO                 13U
#define GPIOA_SWCLK                 14U
#define GPIOA_PIN15_NOT_USED        15U

#define GPIOB_SPI_HOLD              0U
#define GPIOB_VUSB_ADC              1U
#define GPIOB_PIN2_NOT_USED         2U
#define GPIOB_INT1_ADXL             3U
#define GPIOB_INT2_ADXL             4U
#define GPIOB_INT_MPU               5U
#define GPIOB_I2C1_SCL              6U
#define GPIOB_I2C1_SDA              7U
#define GPIOB_PIN8_NOT_USED         8U
#define GPIOB_PIN9_NOT_USED         9U
#define GPIOB_I2C2_SCL              10U
#define GPIOB_I2C2_SDA              11U
#define GPIOB_PIN12_NOT_USED        12U
#define GPIOB_PIN13_NOT_USED        13U
#define GPIOB_LED_4                 14U
#define GPIOB_LED_3                 15U

#define GPIOC_PIN0_NOT_USED         0U
#define GPIOC_PIN1_NOT_USED         1U
#define GPIOC_PIN2_NOT_USED         2U
#define GPIOC_PIN3_NOT_USED         3U
#define GPIOC_PIN4_NOT_USED         4U
#define GPIOC_PIN5_NOT_USED         5U
#define GPIOC_PIN6_NOT_USED         6U
#define GPIOC_PIN7_NOT_USED         7U
#define GPIOC_PIN8_NOT_USED         8U
#define GPIOC_PIN9_NOT_USED         9U
#define GPIOC_PIN10_NOT_USED        10U
#define GPIOC_PIN11_NOT_USED        11U
#define GPIOC_PIN12_NOT_USED        12U
#define GPIOC_USR_BTN_2             13U
#define GPIOC_LED_1                 14U
#define GPIOC_LED_2                 15U

#define GPIOD_PIN0_NOT_USED         0U
#define GPIOD_PIN1_NOT_USED         1U
#define GPIOD_PIN2_NOT_USED         2U
#define GPIOD_PIN3_NOT_USED         3U
#define GPIOD_PIN4_NOT_USED         4U
#define GPIOD_PIN5_NOT_USED         5U
#define GPIOD_PIN6_NOT_USED         6U
#define GPIOD_PIN7_NOT_USED         7U
#define GPIOD_PIN8_NOT_USED         8U
#define GPIOD_PIN9_NOT_USED         9U
#define GPIOD_PIN10_NOT_USED        10U
#define GPIOD_PIN11_NOT_USED        11U
#define GPIOD_PIN12_NOT_USED        12U
#define GPIOD_PIN13_NOT_USED        13U
#define GPIOD_PIN14_NOT_USED        14U
#define GPIOD_PIN15_NOT_USED        15U

#define GPIOE_PIN0_NOT_USED         0U
#define GPIOE_PIN1_NOT_USED         1U
#define GPIOE_PIN2_NOT_USED         2U
#define GPIOE_PIN3_NOT_USED         3U
#define GPIOE_PIN4_NOT_USED         4U
#define GPIOE_PIN5_NOT_USED         5U
#define GPIOE_PIN6_NOT_USED         6U
#define GPIOE_PIN7_NOT_USED         7U
#define GPIOE_PIN8_NOT_USED         8U
#define GPIOE_PIN9_NOT_USED         9U
#define GPIOE_PIN10_NOT_USED        10U
#define GPIOE_PIN11_NOT_USED        11U
#define GPIOE_PIN12_NOT_USED        12U
#define GPIOE_PIN13_NOT_USED        13U
#define GPIOE_PIN14_NOT_USED        14U
#define GPIOE_PIN15_NOT_USED        15U
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

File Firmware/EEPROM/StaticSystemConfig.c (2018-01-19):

#include "ch.h"
#include "hal.h"
#include "ChibiOS/os/hal/lib/streams/chprintf.h"

#include "StaticSystemConfig.h"
#include "SPI_25LC01.h"

uint8_t checkSystemConfig(struct configStructure *sysConfig)
{
	if (sysConfig->magicNumber == VALID_MAGIC)
		return 0;
	else
		return 1;
}

uint8_t restoreSystemConfigEEPROM(const SPIConfig *spiConfig,
				  struct configStructure *sysConfig)
{
	EEPROM_readBytes(&SPID1,
			 spiConfig,
			 0,
			 sizeof(struct configStructure),
			 (uint8_t *)sysConfig);
	return checkSystemConfig(sysConfig);
}

void saveSystemConfigEEPROM(const SPIConfig *spiConfig,
			    struct configStructure *sysConfig)
{
	EEPROM_writeBytes(&SPID1,
			  spiConfig,
			  0,
			  sizeof(struct configStructure),
			  (uint8_t *)sysConfig);
}

void saveDefaultConfigEEPROM(const SPIConfig *spiConfig)
{
	struct configStructure defaultConfig;
	defaultConfig.samplingSpeed = 800;
	defaultConfig.accelerometerRange = 2;
	defaultConfig.calibrationMPU[0] = 0;
	defaultConfig.calibrationMPU[1] = 0;
	defaultConfig.calibrationMPU[2] = 0;
	defaultConfig.calibrationADXL[0] = 0;
	defaultConfig.calibrationADXL[1] = 0;
	defaultConfig.calibrationADXL[2] = 0;
	defaultConfig.gyroActivatedMPU = false;
	defaultConfig.calibrationDelay = 3;
	defaultConfig.acquisitionDelay = 3;
	defaultConfig.magicNumber = VALID_MAGIC;
	defaultConfig.MPUfilterType = 0;
	defaultConfig.ADXLfilterType = 0;
	EEPROM_writeBytes(&SPID1,
			  spiConfig,
			  0,
			  sizeof(struct configStructure),
			  (uint8_t *)&defaultConfig);
}
void printSystemConfig(struct configStructure *sysConfig, BaseSequentialStream *stream)
{
	chprintf(stream, "- - - - - - - - - - - - - - - - - - - -\r\n");
	chprintf(stream, "Calibration MPU: %d %d %d\r\n",
		 sysConfig->calibrationMPU[0],
		 sysConfig->calibrationMPU[1],
		 sysConfig->calibrationMPU[2]);
	chprintf(stream, "Calibration ADXL: %d %d %d\r\n",
		 sysConfig->calibrationADXL[0],
		 sysConfig->calibrationADXL[1],
		 sysConfig->calibrationADXL[2]);
	chprintf(stream, "Magic: 0x%x\r\n", sysConfig->magicNumber);
	chprintf(stream, "Sampling speed: %u\r\n", sysConfig->samplingSpeed);
	chprintf(stream, "Accel range: %u\r\n",
		 (uint16_t)sysConfig->accelerometerRange);
	chprintf(stream, "Calibration delay: %u\r\n",
		 (uint16_t)sysConfig->calibrationDelay);
	chprintf(stream, "Acquisition delay: %u\r\n",
		 (uint16_t)sysConfig->acquisitionDelay);
	chprintf(stream, "MPU filter type: %u\r\n",
		 (uint16_t)sysConfig->MPUfilterType);
	chprintf(stream, "ADXL filter type: %u\r\n",
		 (uint16_t)sysConfig->ADXLfilterType);
	chprintf(stream, "Gyro MPU Activated: %u\r\n",
		 (uint16_t)sysConfig->gyroActivatedMPU);
	chprintf(stream, "- - - - - - - - - - - - - - - - - - - -\r\n");
}

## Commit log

2017-12-05 [Qt] New binary format for target config. Save button CB.
2017-12-05 [Qt] Sensor name is now correct (MPU and ADXL instead of A and B)
2017-12-05 [Qt] Add update port button. Still some layout issues.
2017-12-05 [Fw] Basic drivers for I2C peripherals
2017-12-05 [Fw] Workaround for STM32F1 buggy I2C
2017-12-05 [Fw] Basic working program for BluePill I2C
2017-12-05 [Fw] First draft writing to SPI
2017-12-05 [Fw] First working version, still some issues (oversampling ADXL?)
    [ADXL345.c, MPU6050.c, halconf.h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]
2017-12-05 [Fw] First draft with drivers
2017-12-05 [Fw] Changed for TOROID board
2017-12-05 [Fw] More changes for TOROID board
2017-12-05 [Fw] Fixed I2C lib for STM32F0
2017-12-05 [Fw] Remaining pin configurations in TOROID board
2017-12-05 [Fw] Basic I2C (MPU not working)
    [ADXL345.c, MPU6050.c, board.h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]
2017-12-05 [Fw] I2C basic is now working!
2017-12-05 [Fw] Working SPI RAM
2017-12-05 [Fw] Working buttons (for calibration and acquisition)
2017-12-05 [Fw] Bugfix when acquisitionDelay is 0. Fixed LEDs.
    [main.c]
2017-12-05 [Fw] ADC for battery level working
2017-12-05 [Fw] ADC is now stopped if an error is detected
    [main.c]
2017-12-05 [Fw] Removed bit banged I2C mode
2017-12-05 [Fw] Transmission using serial driver (quite slow)
2017-12-05 [Fw] Improved transmission using serial driver
2017-12-05 [Fw] Better filtering of Serial events (detect keystroke)
2017-12-05 [Fw] Small modifications when coupling board with Qt software
2017-12-05 [Fw] Now using UART driver for UART 1 instead of SERIAL
2017-12-05 [Fw] Led 3 blinks during transmission
2017-12-05 First schematic - accelerometer board
    [PlacaMirasso.sch]
2017-12-05 [Bd] New MCU
    [PlacaMirasso.kicad_pcb, PlacaMirasso.sch]
2017-12-05 [Bd] First PCB draft
    [PlacaMirasso.kicad_pcb, PlacaMirasso.sch]
2017-12-05 [Bd] Second draft
    [PlacaMirasso.kicad_pcb, PlacaMirasso.sch]
2017-12-05 [Bd] Moved PCB into Board directory.
    [PlacaMirasso.kicad_pcb, PlacaMirasso.sch]
2017-12-10 [Qt] increase timeout in serial read, solves Windows problem
    [masterthread.cpp]
2017-12-11 [Fw] systemConfig structure can be changed through UART with 'c' command
2017-12-11 [Qt] UI can now modify (some) board parameters
2017-12-11 [Fw] Firmware now supports sample rate changement
2017-12-12 [Fw] accelerometers supporting different filters
2017-12-12 [Fw] Accelerometers now have an exponential high pass filter. Vector notation for acceleration. volatile used for some config variables.
2017-12-12 [Qt] better UI management. filterType supported in UI.
2017-12-12 [Fw] simpler printSystemConfig function
2017-12-12 [Fw] each accelerometer supports different filters
2017-12-12 [Qt] different filters for each accelerometer
